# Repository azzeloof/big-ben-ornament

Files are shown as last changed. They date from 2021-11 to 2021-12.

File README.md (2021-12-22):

# Big Ben Ornament
 A PCB ornament/desk toy complete with an E-Paper display!

## Hardware
Okay, so this is a bit overkill for an ornament. It uses an ATmega328P to coordinate a Real-Time Clock, some RAM, and the driver circuitry for an E-Paper display. The end result is a pretty damn good looking (and accurate) clock. 
There are several problems- I never connected AVCC on the ATmega, the RESET pin was connected incorrectly, and a transistor in the EPD driver circuit was laid out with the incorrect footprint. My brother helped me resolve all this with some clever bodge, but it would probably be best to actually design the boards properly for future versions.

## Firmware
The clock's firmware is just an Arduino sketch. It requires the Waveshare EPD library, as well as Adafruit's RTClib. The clock face is a bitmap stored in memory, and the hands are dynamically drawn from lines and circles. 
To program the chips, I flashed the arduino bootloader onto the chip and used the ["breadboard Arduino" board file](https://www.arduino.cc/en/Tutorial/BuiltInExamples/ArduinoToBreadboard). I programmed the board with SparkFun's [Pocket AVR Programmer](https://www.sparkfun.com/products/9825), but you should be able to use any programmer compatibe with the ATmega328P (or just use an Arduino Uno!).

## Version History
Release 1.0 will represent the bus ornaments as we initially made and distributed them. Once it is released, maybe we'll improve some stuff (but any hardware improvements will be untested).

## Warning
Electricity creates heat, and excess heat around something like a Christmas tree can cause big problems. Use at your own risk! The designs here have only been minimally tested and are absolutley not guarenteed to be safe.

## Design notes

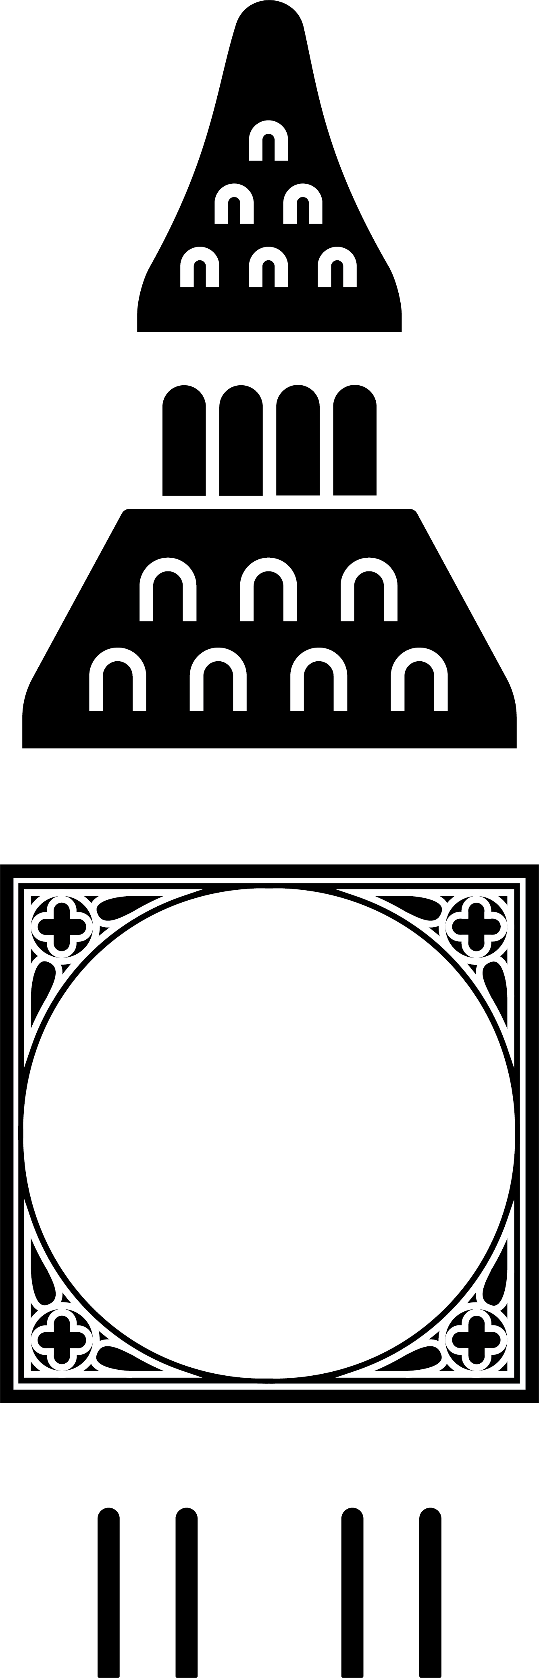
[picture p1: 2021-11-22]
hardware/artwork/big-ben-ornament-silkscreen.png

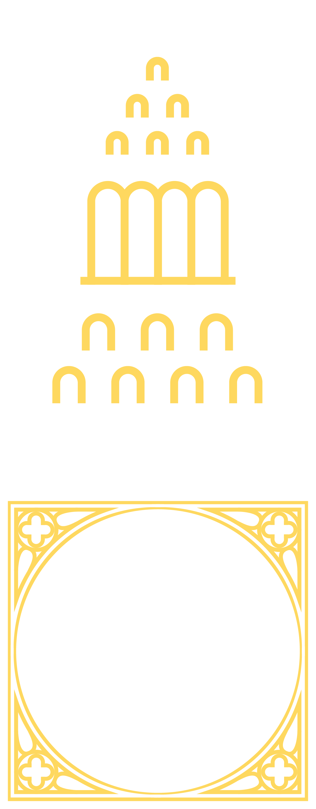
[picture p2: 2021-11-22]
hardware/artwork/big-ben-ornament-mask.png

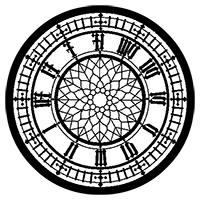
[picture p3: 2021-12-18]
firmware/face.jpg

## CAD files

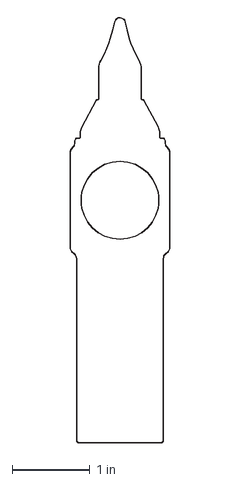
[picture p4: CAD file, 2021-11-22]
hardware/artwork/edge-cuts.dxf
1.28 x 5.48 in

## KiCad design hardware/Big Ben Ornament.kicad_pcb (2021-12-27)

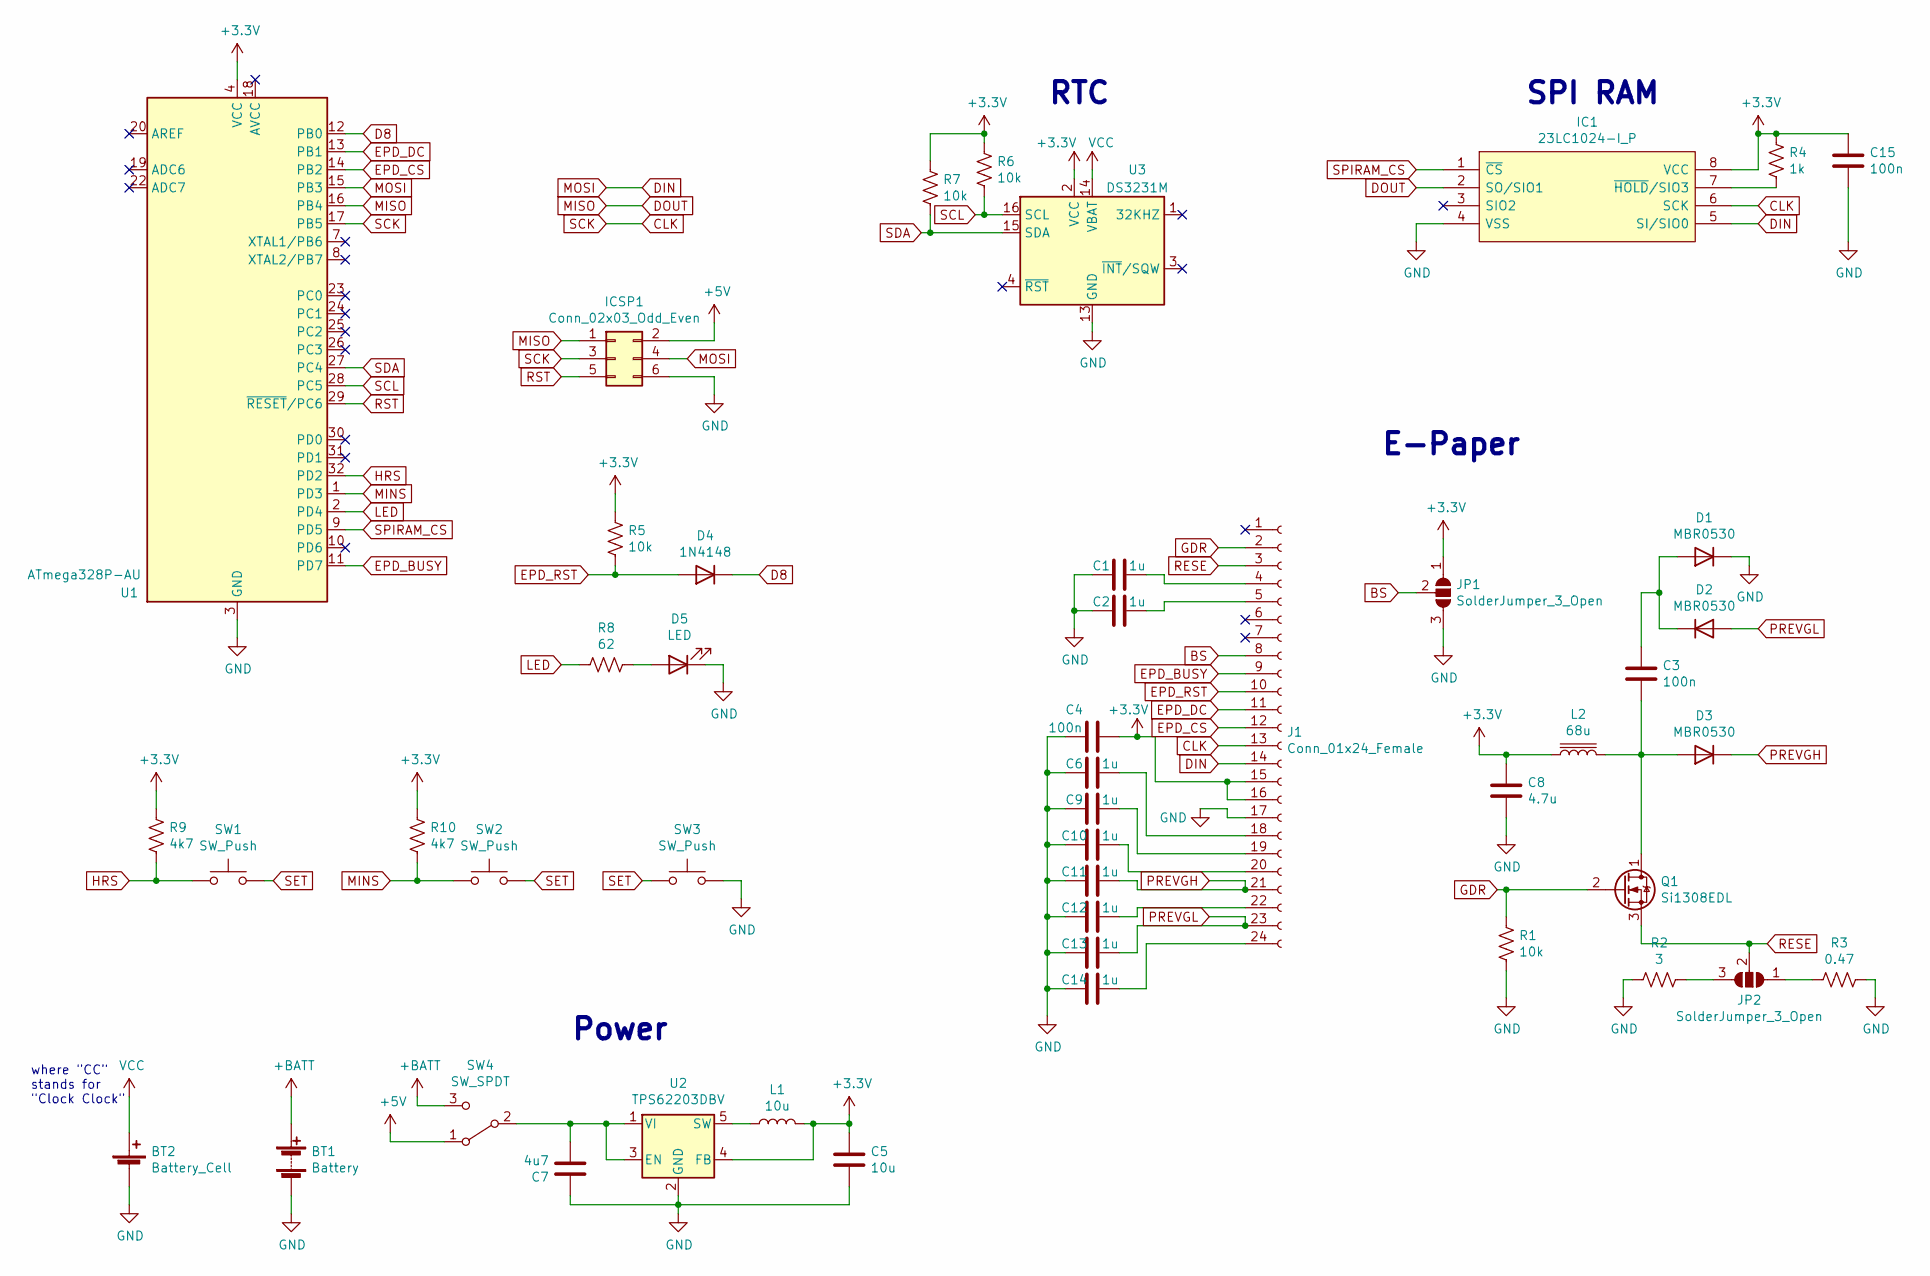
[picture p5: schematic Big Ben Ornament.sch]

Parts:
BT1: Battery; BatteryHolder_Keystone_3002_1x2032
BT2: Battery_Cell; BatteryHolder_Keystone_3000_1x12mm
C1, C2, C6, C9, C10, C11, C12, C13, C14: 1u; C_0805_2012Metric_Pad1.18x1.45mm_HandSolder; Voltage 50
C3: 100n; C_0805_2012Metric_Pad1.18x1.45mm_HandSolder; Voltage 50
C4, C15: 100n; C_0805_2012Metric_Pad1.18x1.45mm_HandSolder
C5: 10u; C_0805_2012Metric_Pad1.18x1.45mm_HandSolder
C7: 4u7; C_0805_2012Metric_Pad1.18x1.45mm_HandSolder
C8: 4.7u; C_0805_2012Metric_Pad1.18x1.45mm_HandSolder
D1, D2, D3: MBR0530; D_SOD-123
D4: 1N4148; D_SOD-123
D5: LED; LED_0805_2012Metric
IC1: 23LC1024-I_P; SOIC-8_3.9x4.9mm_P1.27mm; Mouser Part Number 579-23LC1024-I/P
ICSP1: Conn_02x03_Odd_Even; PinHeader_2x03_P2.54mm_Vertical_SMD
J1: Conn_01x24_Female; TE_2-1734839-4_1x24-1MP_P0.5mm_Horizontal
JP1, JP2: SolderJumper_3_Open; SolderJumper-3_P1.3mm_Open_RoundedPad1.0x1.5mm
L1: 10u; L_Coilcraft_XAL60xx_6.36x6.56mm
L2: 68u; L_Coilcraft_XxL4040
Q1: Si1308EDL; SOT-323_SC-70_Handsoldering
R1, R5, R6, R7: 10k; R_0805_2012Metric_Pad1.20x1.40mm_HandSolder
R2: 3; R_0805_2012Metric_Pad1.20x1.40mm_HandSolder
R3: 0.47; R_0805_2012Metric_Pad1.20x1.40mm_HandSolder
R4: 1k; R_0805_2012Metric_Pad1.20x1.40mm_HandSolder
R8: 62; R_0805_2012Metric_Pad1.20x1.40mm_HandSolder
R9, R10: 4k7; R_0805_2012Metric_Pad1.20x1.40mm_HandSolder
SW1, SW2, SW3: SW_Push; SW_Push_1P1T_NO_CK_KSC6xxJ
SW4: SW_SPDT; SW_SPDT_PCM12
U1: ATmega328P-AU; TQFP-32_7x7mm_P0.8mm
U2: TPS62203DBV; SOT-23-5
U3: DS3231M; SOIC-16W_7.5x10.3mm_P1.27mm

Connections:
+3V3: C4.2, C5.1, C8.1, C15.1, IC1.8 (VCC), J1.15, J1.16, JP1.1 (A), L1.2, L2.1, R4.2, R5.1, R6.1, R7.1, R9.2, R10.2, U1.4 (VCC), U1.6 (VCC), U2.4 (FB), U3.2 (VCC)
+5V: ICSP1.2, SW4.1 (A); also elsewhere on the board
+BATT: BT1.1 (+), SW4.3 (C)
BS: J1.8, JP1.2 (C)
CLK: IC1.6 (SCK), ICSP1.3, J1.13, U1.17 (PB5); also elsewhere on the board
D8: D4.1 (K), U1.12 (PB0)
DIN: IC1.5 (SI/SIO0), ICSP1.4, J1.14, U1.15 (PB3); also elsewhere on the board
DOUT: IC1.2 (SO/SIO1), ICSP1.1, U1.16 (PB4); also elsewhere on the board
EPD_BUSY: J1.9, U1.11 (PD7)
EPD_CS: J1.12, U1.14 (PB2)
EPD_DC: J1.11, U1.13 (PB1)
EPD_RST: D4.2 (A), J1.10, R5.2
GDR: J1.2, Q1.2 (G), R1.1
GND: BT1.2 (-), BT2.2 (-), C1.2, C2.1, C4.1, C5.2, C6.1, C7.1, C8.2, C9.1, C10.1, C11.1, C12.1, C13.1, C14.1, C15.2, D1.1 (K), D5.1 (K), IC1.4 (VSS), ICSP1.6, J1.17, JP1.3 (B), R1.2, R2.1, R3.2, SW3.2, U1.3 (GND), U1.5 (GND), U1.21 (GND), U2.2 (GND), U3.5 (GND), U3.6 (GND), U3.7 (GND), U3.8 (GND), U3.9 (GND), U3.10 (GND), U3.11 (GND), U3.12 (GND), U3.13 (GND); also elsewhere on the board
HRS: R9.1, SW1.1, U1.32 (PD2)
LED: R8.2, U1.2 (PD4)
MINS: R10.1, SW2.1, U1.1 (PD3)
unnamed: C1.1, J1.4
unnamed: C2.2, J1.5
unnamed: C3.1, D1.2 (A), D2.1 (K)
unnamed: C3.2, D3.2 (A), L2.2, Q1.1 (D)
unnamed: C6.2, J1.18
unnamed: C7.2, SW4.2 (B), U2.1 (VI), U2.3 (EN)
unnamed: C9.2, J1.19
unnamed: C10.2, J1.20
unnamed: C12.2, J1.22
unnamed: C14.2, J1.24
unnamed: D5.2 (A), R8.1
unnamed: IC1.7 (~HOLD~/SIO3), R4.1
unnamed: JP2.1 (A), R3.1
unnamed: JP2.3 (B), R2.2
unnamed: L1.1, U2.5 (SW)
PREVGH: C11.2, D3.1 (K), J1.21
PREVGL: C13.2, D2.2 (A), J1.23
RESE: J1.3, JP2.2 (C), Q1.3 (S)
RST: ICSP1.5, U1.29 (~RESET~/PC6); also elsewhere on the board
SCL: R6.2, U1.28 (PC5), U3.16 (SCL)
SDA: R7.2, U1.27 (PC4), U3.15 (SDA)
SET: SW1.2, SW2.2, SW3.1
SPIRAM_CS: IC1.1 (~CS), U1.9 (PD5)
VCC: BT2.1 (+), U3.14 (VBAT)

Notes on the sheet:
SPI RAM
Power
E-Paper
RTC
where "CC" stands for "Clock Clock"

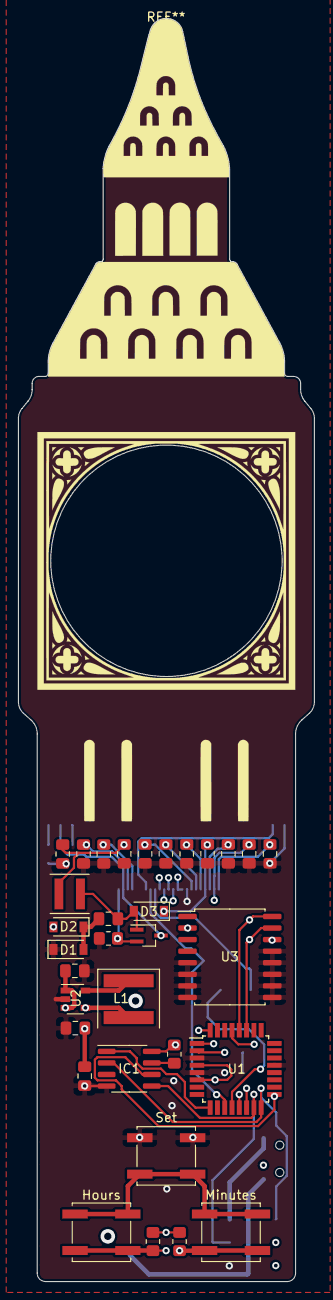
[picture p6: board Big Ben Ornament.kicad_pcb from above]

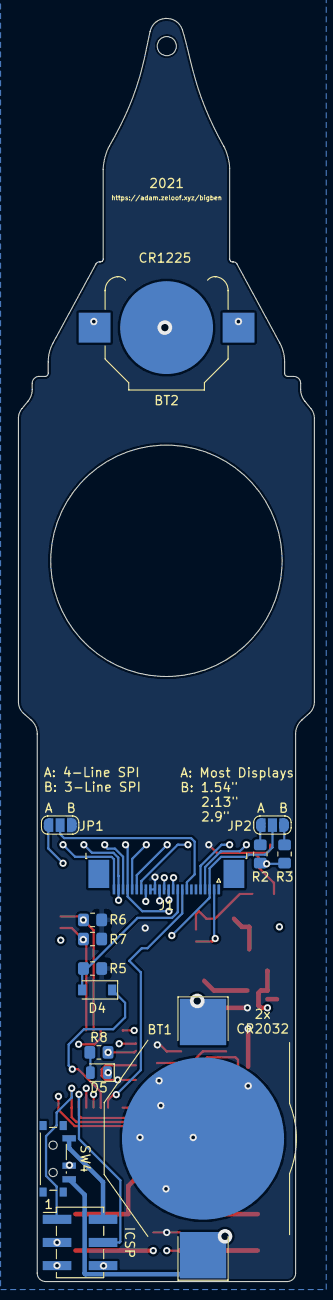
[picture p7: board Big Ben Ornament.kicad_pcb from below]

Board: 4 copper layers, 32.5 x 138.7 mm, 47 parts (15 on the bottom side), 41 nets.

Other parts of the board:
ICSP: Conn_02x03_Odd_Even; PinHeader_2x03_P2.54mm_Vertical_SMD

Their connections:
+5V: ICSP.2; also elsewhere on the board
CLK: ICSP.3; also elsewhere on the board
DIN: ICSP.4; also elsewhere on the board
DOUT: ICSP.1; also elsewhere on the board
GND: ICSP.6; also elsewhere on the board
RST: ICSP.5; also elsewhere on the board

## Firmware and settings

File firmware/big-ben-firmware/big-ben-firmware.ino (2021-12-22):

#include "RTClib.h"
#include "EPD.h"
#include "GUI_Paint.h"
#include "face.h"
#include "math.h"

#define WIDTH 200
#define HEIGHT 200

const int hourPin = 2;
const int minutePin = 3;

RTC_DS3231 rtc;

long lastMillis = -60000;
int hourButtonState = 0;
int minuteButtonState = 0;

void drawHourHand(int hour, int minute) {
  int xc = WIDTH/2;
  int yc = HEIGHT/2;
  int l = 40;
  int w = 4;
  float adjustedHour = hour + minute / 60.0;
  double theta = M_PI - adjustedHour*M_PI/6;
  int xTip = xc+int(l*sin(theta));
  int yTip = yc+int(l*cos(theta));
  int xBase1 = xc+int(w*sin(theta+M_PI/2));
  int yBase1 = yc+int(w*cos(theta+M_PI/2));
  int xBase2 = xc+int(w*sin(theta-M_PI/2));
  int yBase2 = yc+int(w*cos(theta-M_PI/2));
  Paint_DrawLine(xc, yc, xTip, yTip, BLACK, LINE_STYLE_SOLID, DOT_PIXEL_2X2);
  Paint_DrawLine(xc, yc, xBase1, yBase1, BLACK, LINE_STYLE_SOLID, DOT_PIXEL_2X2);
  Paint_DrawLine(xBase1, yBase1, xTip, yTip, BLACK, LINE_STYLE_SOLID, DOT_PIXEL_2X2);
  Paint_DrawLine(xc, yc, xBase2, yBase2, BLACK, LINE_STYLE_SOLID, DOT_PIXEL_2X2);
  Paint_DrawLine(xBase2, yBase2, xTip, yTip, BLACK, LINE_STYLE_SOLID, DOT_PIXEL_2X2);
  Paint_DrawCircle(xc, yc, 8, BLACK, DRAW_FILL_FULL, DOT_PIXEL_1X1);
}

void drawMinuteHand(int minute) {
  int xc = WIDTH/2;
  int yc = HEIGHT/2;
  int lA = 70;
  int lB = 15;
  double theta = M_PI - minute*M_PI/30;
  int xTipA = xc+int(lA*sin(theta));
  int yTipA = yc+int(lA*cos(theta));
  int xTipB = xc-int(lB*sin(theta));
  int yTipB = yc-int(lB*cos(theta));
  Paint_DrawLine(xTipA, yTipA, xTipB, yTipB, BLACK, LINE_STYLE_SOLID, DOT_PIXEL_2X2);
}

void setup() {
  pinMode(hourPin, INPUT);
  pinMode(minutePin, INPUT);
  rtc.begin();
  //rtc.adjust(DateTime(2021, 12, 18, 9, 17, 0));

  DEV_Module_Init();
  EPD_1IN54_V2_Init();
  EPD_1IN54_V2_Clear();
  DEV_Delay_ms(500);
}

DateTime now;

void loop() {
  hourButtonState = digitalRead(hourPin);
  minuteButtonState = digitalRead(minutePin);
  if (hourButtonState == LOW) {
    now = rtc.now();
    rtc.adjust(DateTime(now.year(), now.month(), now.day(), now.hour()+1, now.minute(), now.second()));
    lastMillis = -60000;
  }
  if (minuteButtonState == LOW) {
    now = rtc.now();
    rtc.adjust(DateTime(now.year(), now.month(), now.day(), now.hour(), now.minute()+1, now.second()));
    lastMillis = -60000;
  }
  if(millis() - lastMillis > 60000) {
    lastMillis = millis();
    now = rtc.now();
    Paint_NewImage(IMAGE_BW, EPD_1IN54_V2_WIDTH, EPD_1IN54_V2_HEIGHT, IMAGE_ROTATE_0, IMAGE_COLOR_POSITIVE);
    Paint_Clear(WHITE);   
    
    Paint_DrawBitMap(FACE);
    drawHourHand(now.twelveHour(), now.minute());
    drawMinuteHand(now.minute());
    
    EPD_1IN54_V2_Display();
  }
}

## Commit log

2021-11-22 Layout finished, gerbers generated
    [Big Ben Ornament-B_Cu.gbl, Big Ben Ornament-B_Mask.gbs, Big Ben Ornament-B_Paste.gbp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]
2021-12-13 Commit prep
    [Big Ben Ornament.kicad_pcb, Big Ben Ornament.sch]
2021-12-27 added HTML BOM
    [Big Ben Ornament.kicad_pcb]
